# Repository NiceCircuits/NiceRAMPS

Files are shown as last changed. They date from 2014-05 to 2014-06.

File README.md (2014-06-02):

ramps_plus
==========
Forked from Ramps 1.4.

Improved version of RAMPS board with ribbon cable connecors and more.

Change log from Ramps 1.4:

- a few ribbon header connectors instead of many pinheaders

- schematic in KiCad

- compatibility with Arduino Due

- separate power supplies for heaters, bed and motors

- 0,5A OC outputs for driwing LED/fans

- SMT power transistors

- blade fuses

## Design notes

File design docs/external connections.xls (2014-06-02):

1 | heater1+ |  | Carriage | bed+ | panel
2 |  |  |  | bed-
3 | heater1- |  |  | bed_th
4 |  |  |  | bed_th
5 | heater2+ |  |  | endstopY
6 |  |  |  | endstopZ
7 | heater2- | g |  | motorY
8 |  |  |  | motorZ
9 | motorE1 |  |  | pwm led
10 | motorE1 |  |  | pwm fan
11 | motorE1 |  |  | pwm fan
12 | motorE1 |  |  | pwm fan
13 | motorE2
14 | motorE2
15 | motorE2
16 | motorE2
17 | pwm1 | fan1
18 | pwm2 | fan2
19 | pwm3 | fan3
20 | pwm4 | led
21 | pwm+
22 | pwm+
23 | GND-N.C.
24 | thermistor-
25 | thermistor1
26 | thermistor2
27 | endstop-
28 | endstop+
29 | endstopX1
30 | endstopX2
31 | motorX |  | Xstop
32 | motorX
33 | motorX
34 | motorX

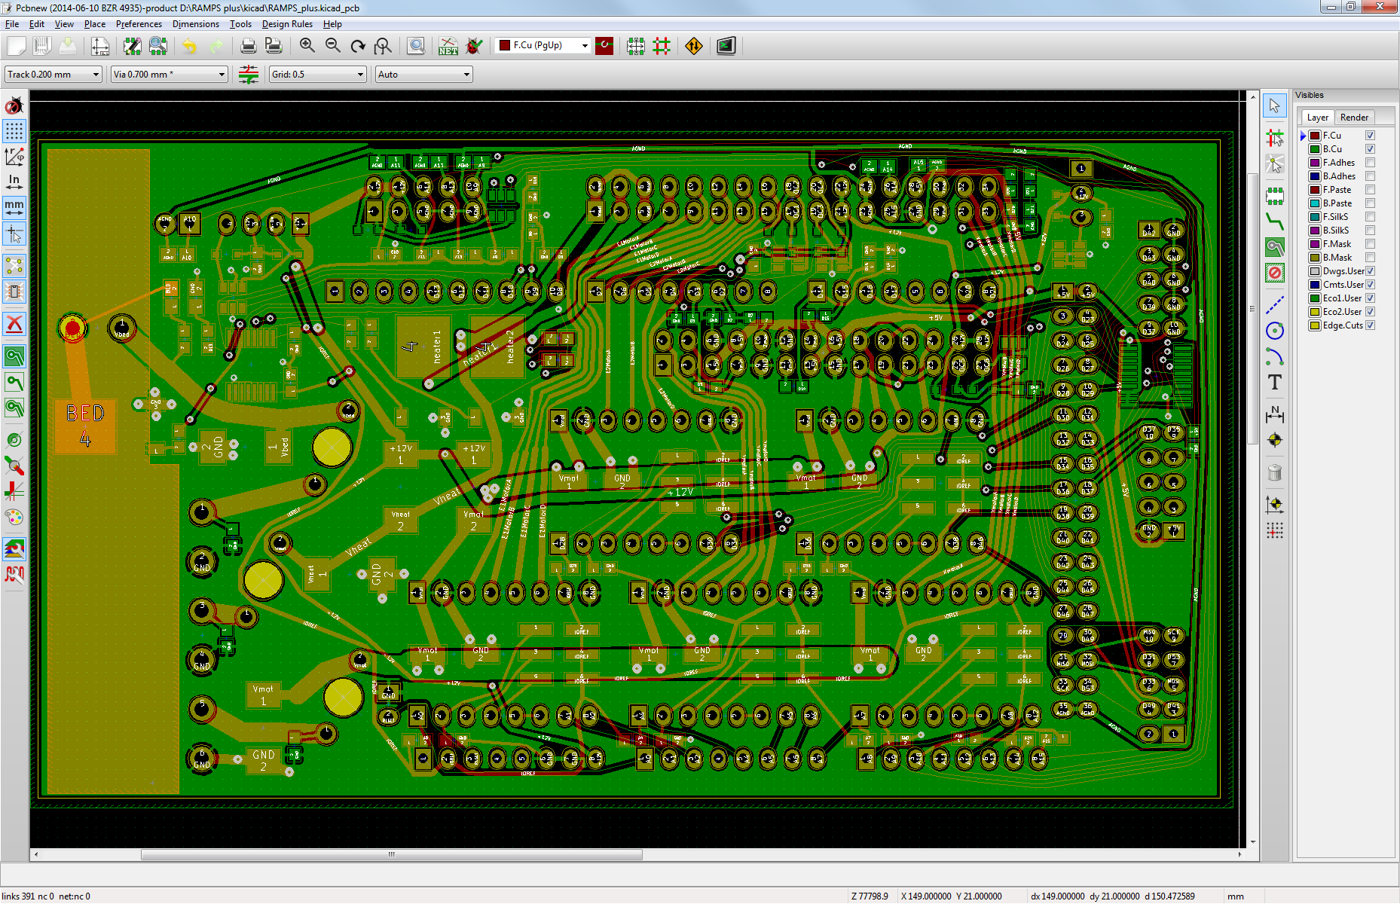
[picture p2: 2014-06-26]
kicad/routing.png

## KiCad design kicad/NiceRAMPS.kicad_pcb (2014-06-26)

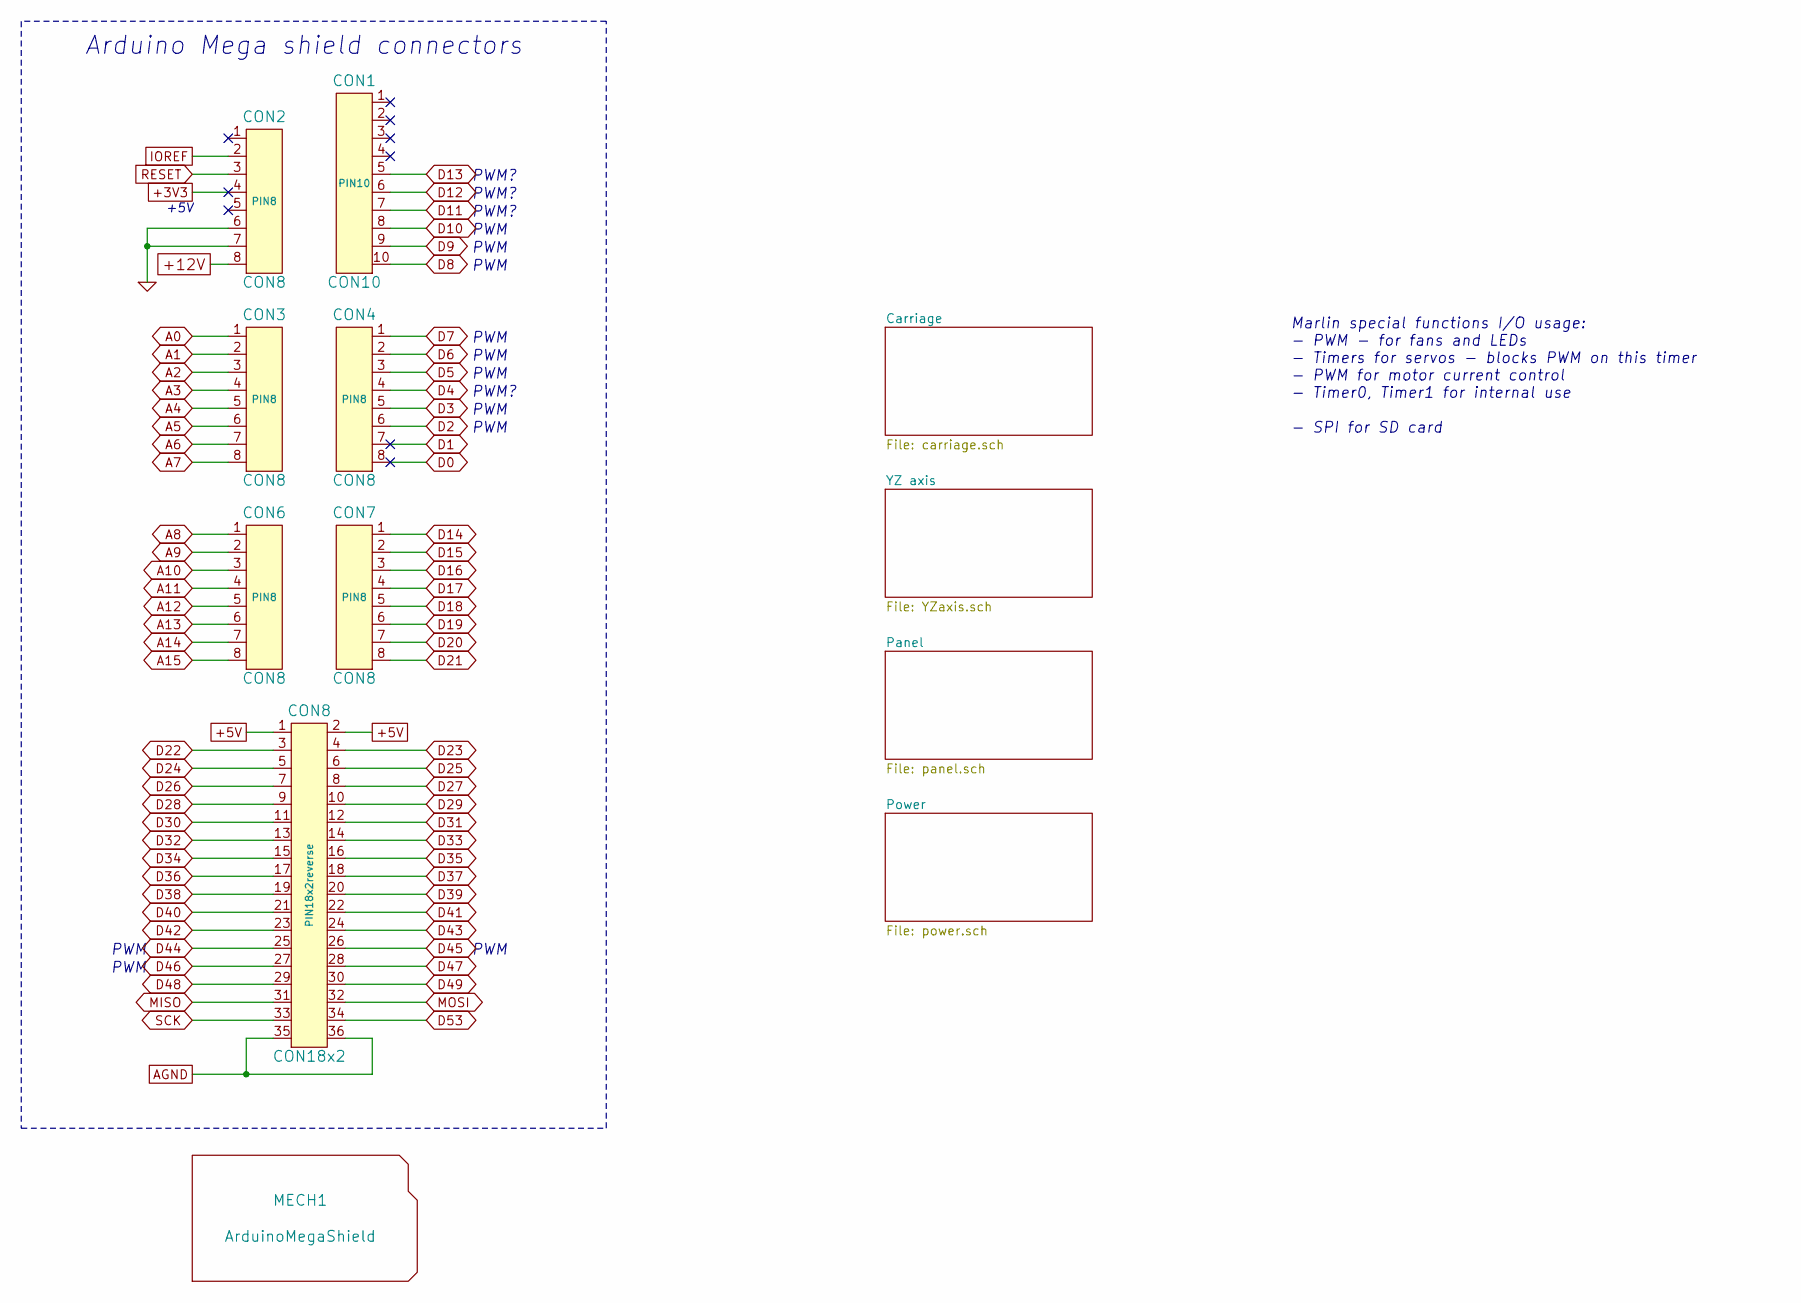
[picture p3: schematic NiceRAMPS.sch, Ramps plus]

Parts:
CON1: CON10; PIN10
CON2, CON3, CON4, CON6, CON7: CON8; PIN8
CON8: CON18x2; PIN18x2reverse
MECH1: ArduinoMegaShield

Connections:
+5V: CON8.1, CON8.2; also elsewhere on the board
+12V: CON2.8; also elsewhere on the board
A0: CON3.1; also elsewhere on the board
A1: CON3.2; also elsewhere on the board
A2: CON3.3; also elsewhere on the board
A4: CON3.5; also elsewhere on the board
A5: CON3.6; also elsewhere on the board
A6: CON3.7; also elsewhere on the board
A7: CON3.8; also elsewhere on the board
A8: CON6.1; also elsewhere on the board
A9: CON6.2; also elsewhere on the board
A10: CON6.3; also elsewhere on the board
A11: CON6.4; also elsewhere on the board
A12: CON6.5; also elsewhere on the board
A13: CON6.6; also elsewhere on the board
A14: CON6.7; also elsewhere on the board
A15: CON6.8; also elsewhere on the board
AGND: CON8.35, CON8.36; also elsewhere on the board
D2: CON4.6; also elsewhere on the board
D3: CON4.5; also elsewhere on the board
D4: CON4.4; also elsewhere on the board
D5: CON4.3; also elsewhere on the board
D6: CON4.2; also elsewhere on the board
D7: CON4.1; also elsewhere on the board
D8: CON1.10; also elsewhere on the board
D9: CON1.9; also elsewhere on the board
D10: CON1.8; also elsewhere on the board
D11: CON1.7; also elsewhere on the board
D12: CON1.6; also elsewhere on the board
D13: CON1.5; also elsewhere on the board
D14: CON7.1; also elsewhere on the board
D15: CON7.2; also elsewhere on the board
D16: CON7.3; also elsewhere on the board
D17: CON7.4; also elsewhere on the board
D20: CON7.7; also elsewhere on the board
D21: CON7.8; also elsewhere on the board
D23: CON8.4; also elsewhere on the board
D24: CON8.5; also elsewhere on the board
D25: CON8.6; also elsewhere on the board
D26: CON8.7; also elsewhere on the board
D27: CON8.8; also elsewhere on the board
D28: CON8.9; also elsewhere on the board
D29: CON8.10; also elsewhere on the board
D30: CON8.11; also elsewhere on the board
D31: CON8.12; also elsewhere on the board
D32: CON8.13; also elsewhere on the board
D33: CON8.14; also elsewhere on the board
D34: CON8.15; also elsewhere on the board
D35: CON8.16; also elsewhere on the board
D36: CON8.17; also elsewhere on the board
D37: CON8.18; also elsewhere on the board
D38: CON8.19; also elsewhere on the board
D39: CON8.20; also elsewhere on the board
D40: CON8.21; also elsewhere on the board
D41: CON8.22; also elsewhere on the board
D42: CON8.23; also elsewhere on the board
D43: CON8.24; also elsewhere on the board
D44: CON8.25; also elsewhere on the board
D45: CON8.26; also elsewhere on the board
D46: CON8.27; also elsewhere on the board
D47: CON8.28; also elsewhere on the board
D49: CON8.30; also elsewhere on the board
D53: CON8.34; also elsewhere on the board
GND: CON2.6, CON2.7; also elsewhere on the board
IOREF: CON2.2; also elsewhere on the board
MISO: CON8.31; also elsewhere on the board
MOSI: CON8.32; also elsewhere on the board
RESET: CON2.3; also elsewhere on the board
SCK: CON8.33; also elsewhere on the board

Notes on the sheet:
Arduino Mega shield connectors
PWM
Marlin special functions I/O usage: - PWM - for fans and LEDs - Timers for servos - blocks PWM on this timer - PWM for motor current control - Timer0, Timer1 for internal use - SPI for SD card
PWM?
+5V

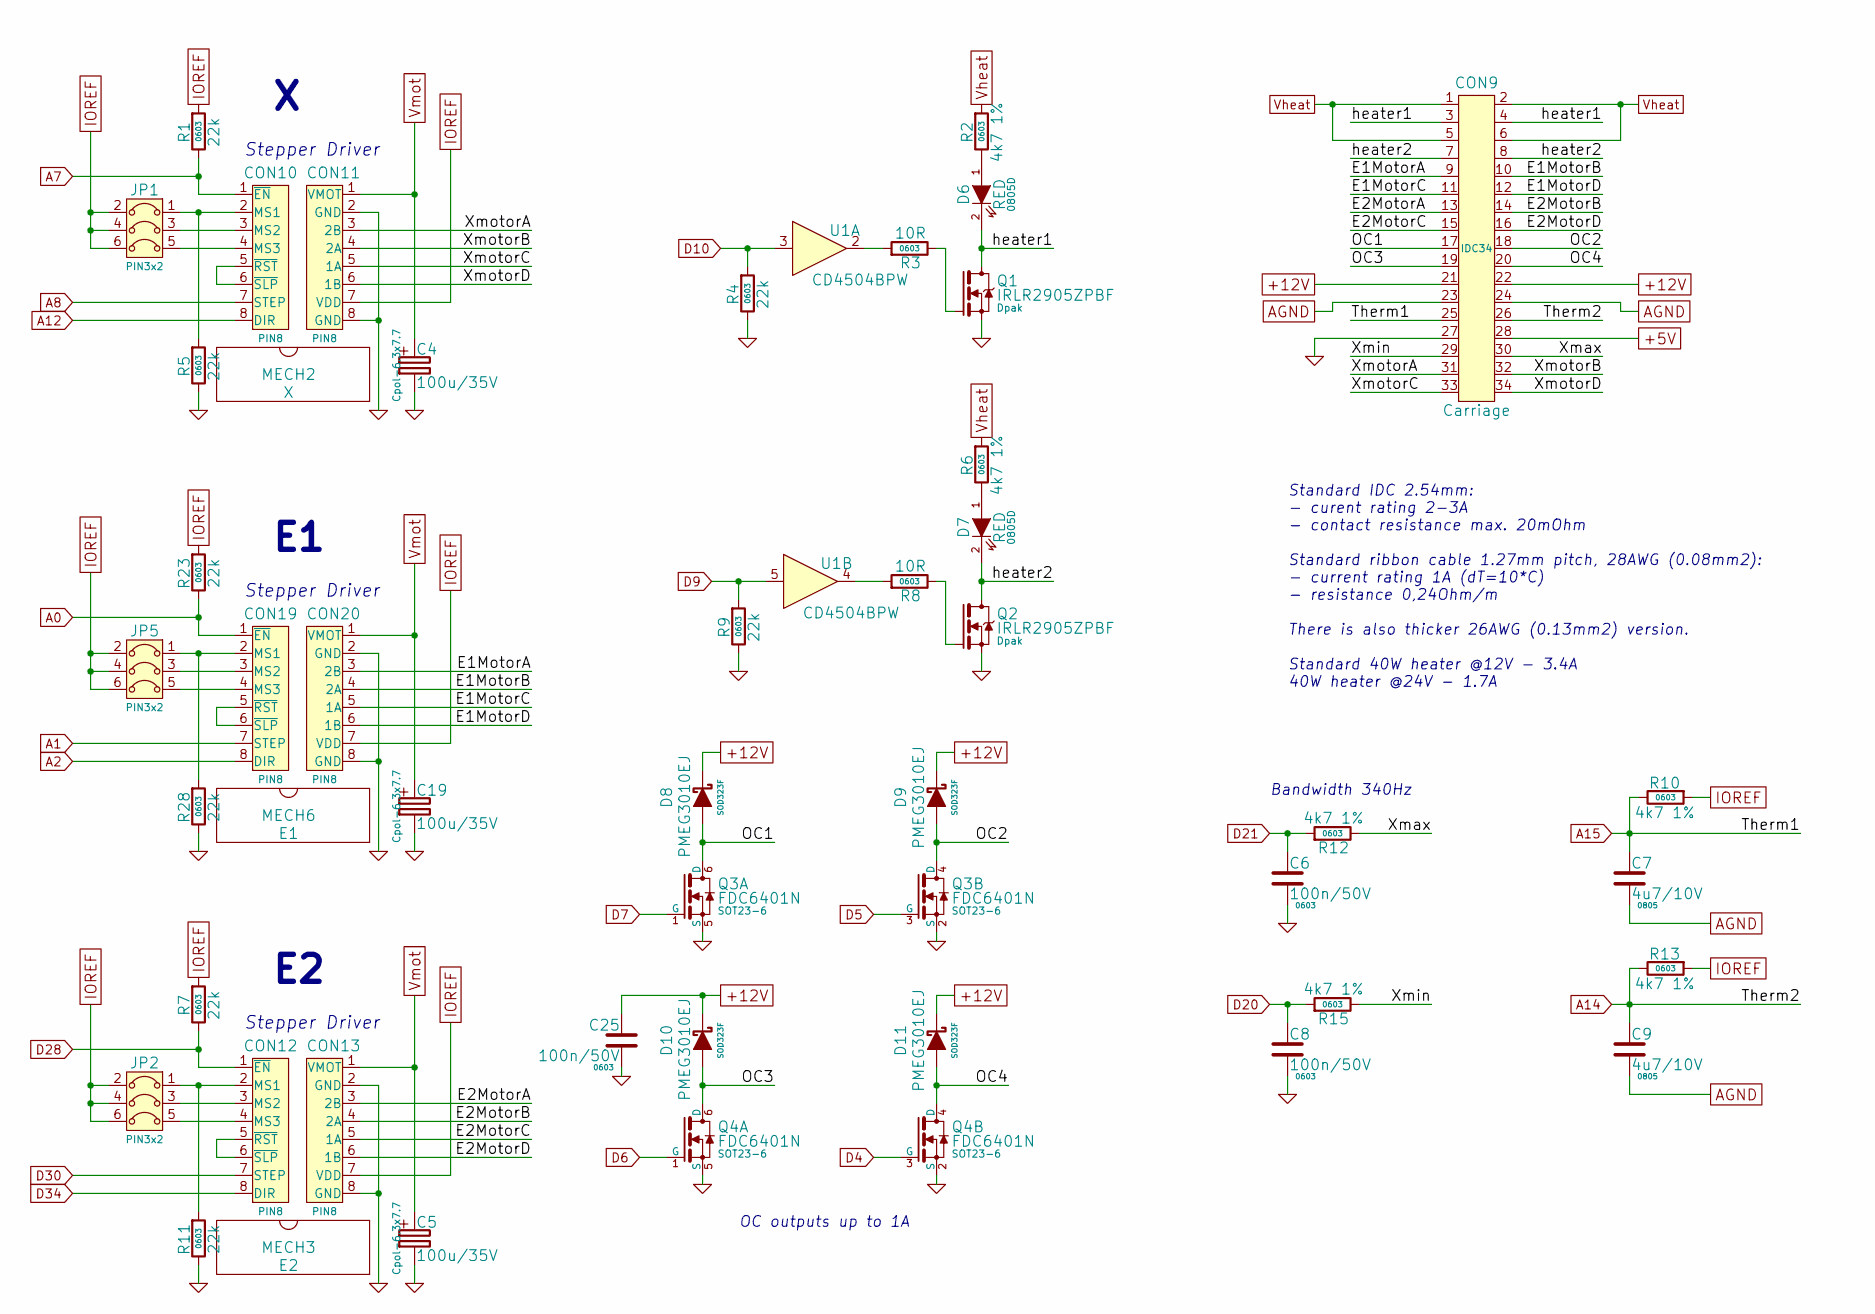
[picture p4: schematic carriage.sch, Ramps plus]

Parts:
C4, C5, C19: 100u/35V; Cpol-6.3x7.7
C6, C8, C25: 100n/50V; 0603
C7, C9: 4u7/10V; 0805
CON9: Carriage; IDC34
CON10, CON12, CON19: Stepstick_Left_Connector; PIN8
CON11, CON13, CON20: Stepstick_Right_Connector; PIN8
D6, D7: RED; 0805D
D8, D9, D10, D11: PMEG3010EJ; SOD323F
JP1, JP2, JP5: Jumper3; PIN3x2
MECH2: X
MECH3: E2
MECH6: E1
Q1, Q2: IRLR2905ZPBF; Dpak
Q3, Q4: FDC6401N; SOT23-6
R1, R4, R5, R7, R9, R11, R23, R28: 22k; 0603
R2, R6, R10, R12, R13, R15: 4k7 1%; 0603
R3, R8: 10R; 0603
U1: CD4504BPW; TSSOP16

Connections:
+5V: CON9.28; also elsewhere on the board
+12V: C25.1, CON9.21, CON9.22, D8.1, D9.1, D10.1, D11.1; also elsewhere on the board
/Carriage/E1MotorA: CON9.9, CON20.3 (2B)
/Carriage/E1MotorB: CON9.10, CON20.4 (2A)
/Carriage/E1MotorC: CON9.11, CON20.5 (1A)
/Carriage/E1MotorD: CON9.12, CON20.6 (1B)
/Carriage/E2MotorA: CON9.13, CON13.3 (2B)
/Carriage/E2MotorB: CON9.14, CON13.4 (2A)
/Carriage/E2MotorC: CON9.15, CON13.5 (1A)
/Carriage/E2MotorD: CON9.16, CON13.6 (1B)
/Carriage/OC1: CON9.17, D8.2, Q3.6 (D)
/Carriage/OC2: CON9.18, D9.2, Q3.4 (D)
/Carriage/OC3: CON9.19, D10.2, Q4.6 (D)
/Carriage/OC4: CON9.20, D11.2, Q4.4 (D)
/Carriage/Xmax: CON9.30, R12.2
/Carriage/Xmin: CON9.29, R15.2
/Carriage/XmotorA: CON9.31, CON11.3 (2B)
/Carriage/XmotorB: CON9.32, CON11.4 (2A)
/Carriage/XmotorC: CON9.33, CON11.5 (1A)
/Carriage/XmotorD: CON9.34, CON11.6 (1B)
/Carriage/heater1: CON9.3, CON9.4, D6.2 (K), Q1.4 (D)
/Carriage/heater2: CON9.7, CON9.8, D7.2 (K), Q2.4 (D)
A0: CON19.1 (~EN), R23.2; also elsewhere on the board
A1: CON19.7 (STEP); also elsewhere on the board
A2: CON19.8 (DIR); also elsewhere on the board
A7: CON10.1 (~EN), R1.2; also elsewhere on the board
A8: CON10.7 (STEP); also elsewhere on the board
A12: CON10.8 (DIR); also elsewhere on the board
A14: C9.1, CON9.26, R13.2; also elsewhere on the board
A15: C7.1, CON9.25, R10.2; also elsewhere on the board
AGND: C7.2, C9.2, CON9.23, CON9.24; also elsewhere on the board
D4: Q4.3 (G); also elsewhere on the board
D5: Q3.3 (G); also elsewhere on the board
D6: Q4.1 (G); also elsewhere on the board
D7: Q3.1 (G); also elsewhere on the board
D9: R9.1, U1.5 (IN2); also elsewhere on the board
D10: R4.1, U1.3 (IN1); also elsewhere on the board
D20: C8.1, R15.1; also elsewhere on the board
D21: C6.1, R12.1; also elsewhere on the board
D28: CON12.1 (~EN), R7.2; also elsewhere on the board
D30: CON12.7 (STEP); also elsewhere on the board
D34: CON12.8 (DIR); also elsewhere on the board
GND: C4.2, C5.2, C6.2, C8.2, C19.2, C25.2, CON9.27, CON11.2 (GND), CON11.8 (GND), CON13.2 (GND), CON13.8 (GND), CON20.2 (GND), CON20.8 (GND), Q1.3 (S), Q2.3 (S), Q3.2 (S), Q3.5 (S), Q4.2 (S), Q4.5 (S), R4.2, R5.2, R9.2, R11.2, R28.2; also elsewhere on the board
IOREF: CON11.7 (VDD), CON13.7 (VDD), CON20.7 (VDD), JP1.2, JP1.4, JP1.6, JP2.2, JP2.4, JP2.6, JP5.2, JP5.4, JP5.6, R1.1, R7.1, R10.1, R13.1, R23.1; also elsewhere on the board
unnamed: CON10.2 (MS1), JP1.1, R5.1
unnamed: CON10.3 (MS2), JP1.3
unnamed: CON10.4 (MS3), JP1.5
unnamed: CON10.5 (~RST), CON10.6 (~SLP)
unnamed: CON12.2 (MS1), JP2.1, R11.1
unnamed: CON12.3 (MS2), JP2.3
unnamed: CON12.4 (MS3), JP2.5
unnamed: CON12.5 (~RST), CON12.6 (~SLP)
unnamed: CON19.2 (MS1), JP5.1, R28.1
unnamed: CON19.3 (MS2), JP5.3
unnamed: CON19.4 (MS3), JP5.5
unnamed: CON19.5 (~RST), CON19.6 (~SLP)
unnamed: D6.1 (A), R2.2
unnamed: D7.1 (A), R6.2
unnamed: Q1.1 (G), R3.2
unnamed: Q2.1 (G), R8.2
unnamed: R3.1, U1.2 (OUT1)
unnamed: R8.1, U1.4 (OUT2)
Vheat: CON9.1, CON9.2, CON9.5, CON9.6, R2.1, R6.1; also elsewhere on the board
Vmot: C4.1, C5.1, C19.1, CON11.1 (VMOT), CON13.1 (VMOT), CON20.1 (VMOT); also elsewhere on the board

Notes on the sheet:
Standard IDC 2.54mm: - curent rating 2-3A - contact resistance max. 20mOhm Standard ribbon cable 1.27mm pitch, 28AWG (0.08mm2): - current rating 1A (dT=10*C) - resistance 0,24Ohm/m There is also thicker 26AWG (0.13mm2) version. Standard 40W heater @12V - 3.4A 40W heater @24V - 1.7A
Bandwidth 340Hz
OC outputs up to 1A
Stepper Driver

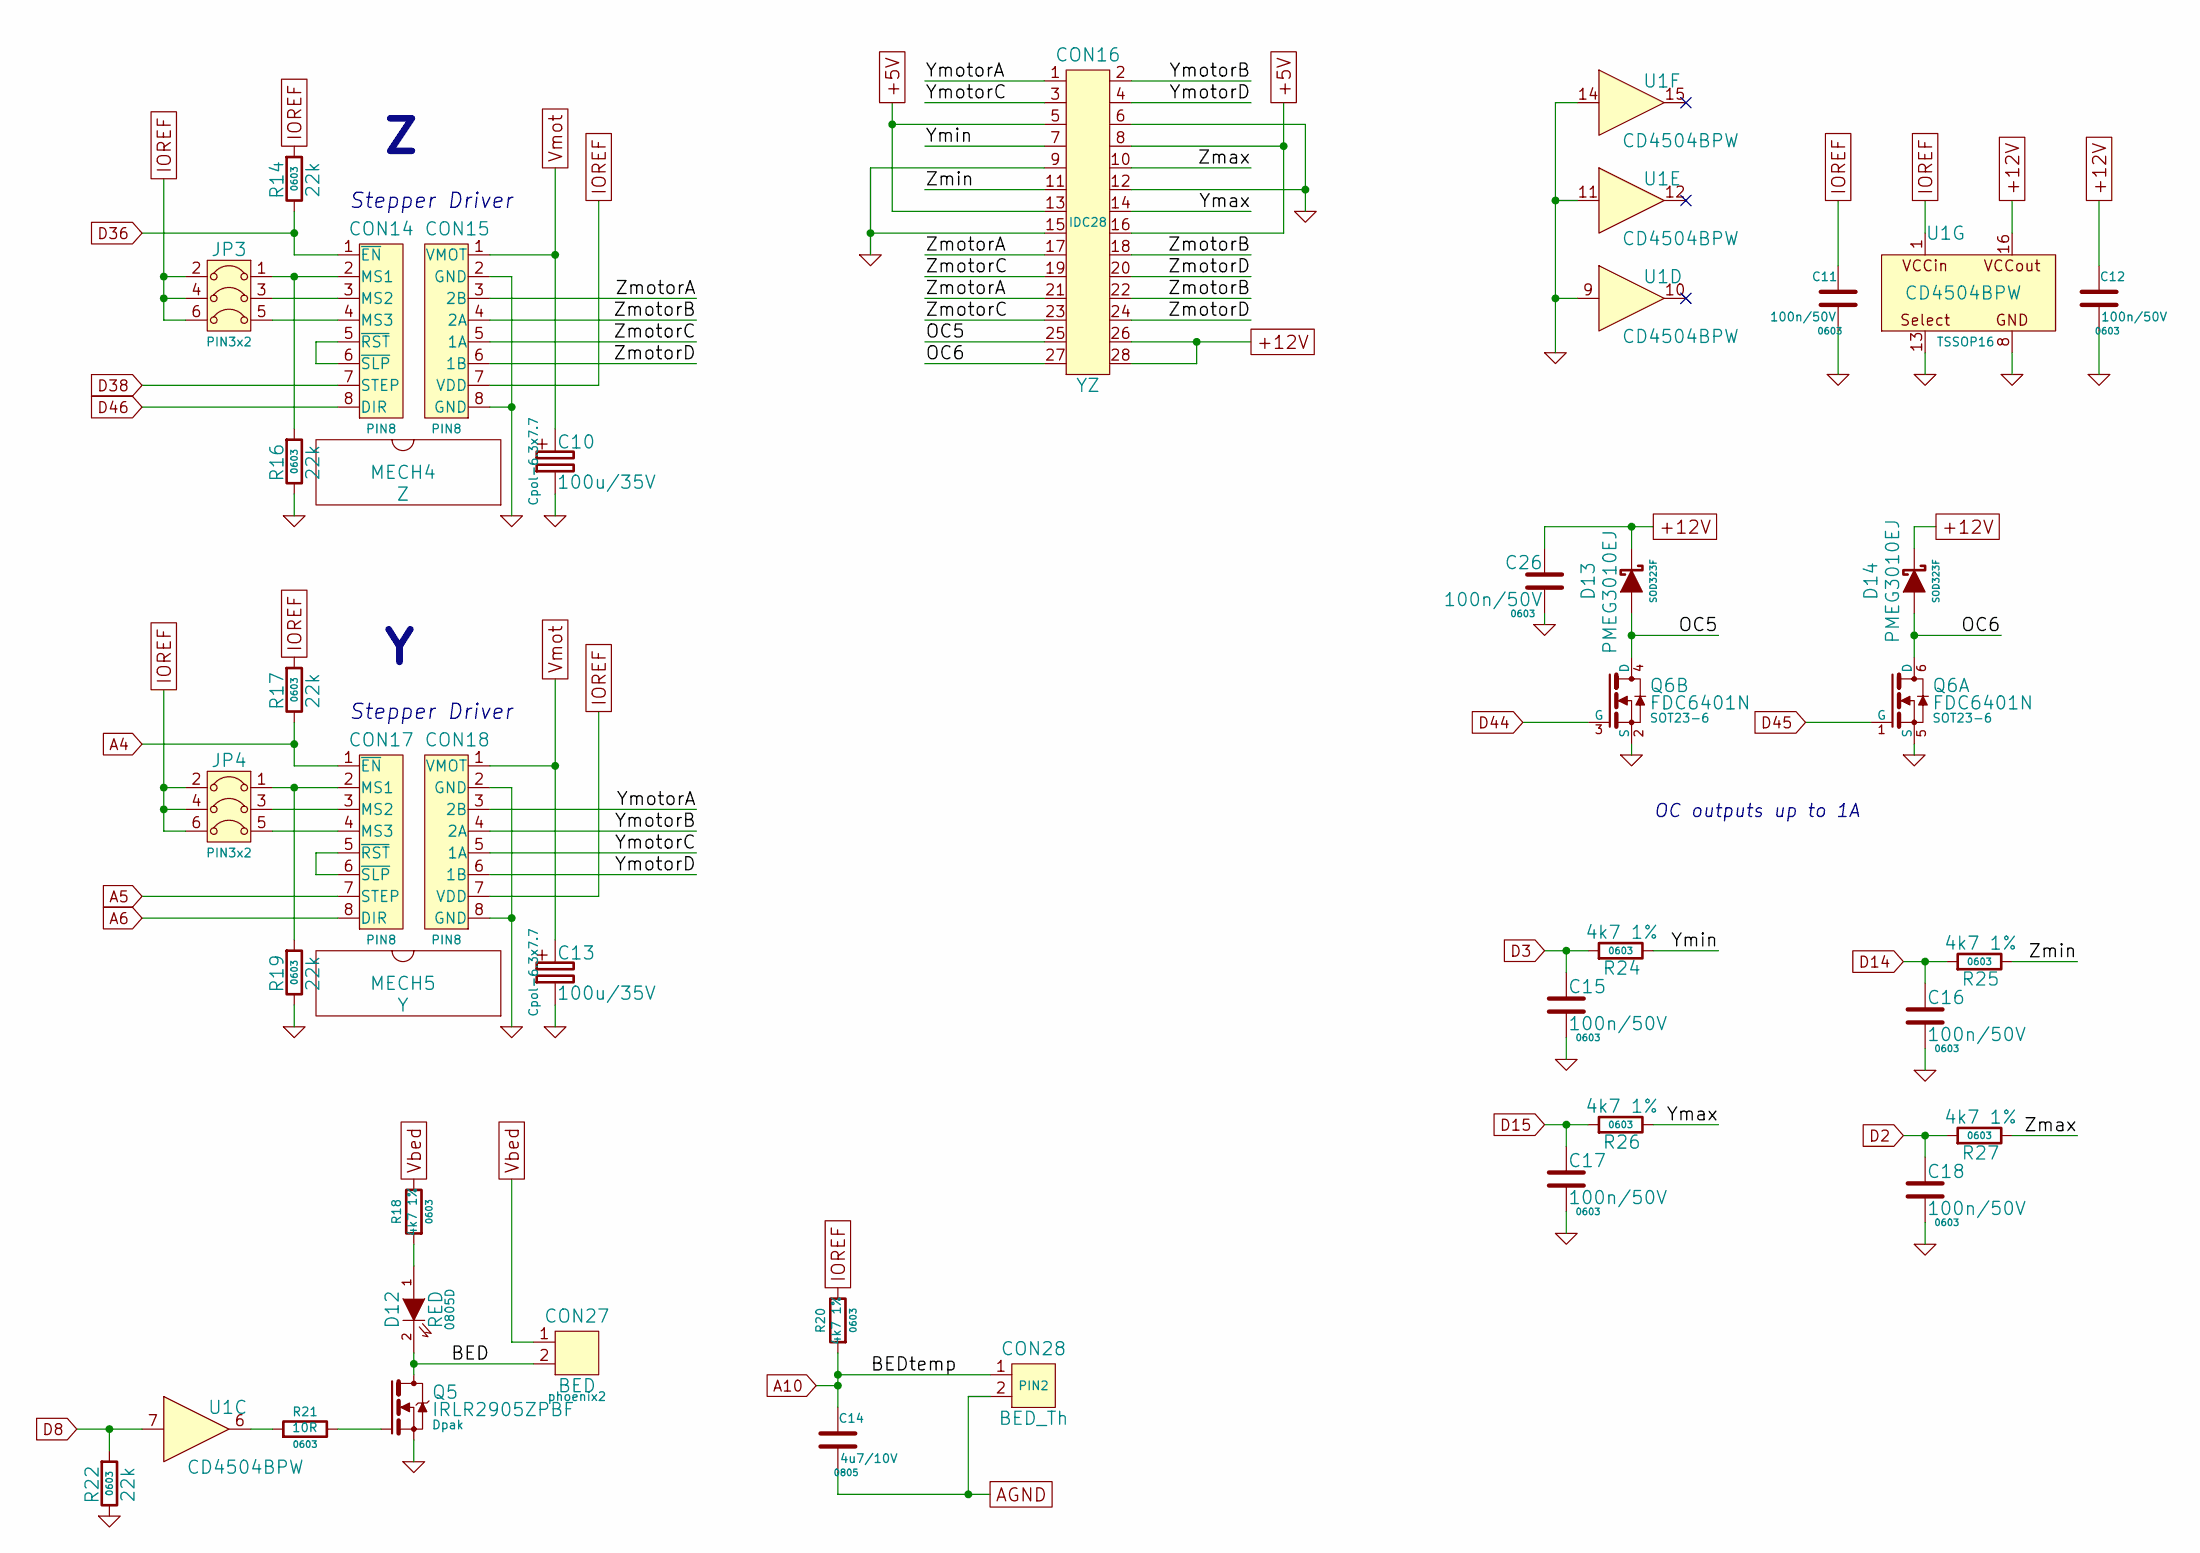
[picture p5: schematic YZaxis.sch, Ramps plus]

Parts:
C10, C13: 100u/35V; Cpol-6.3x7.7
C11, C12, C15, C16, C17, C18, C26: 100n/50V; 0603
C14: 4u7/10V; 0805
CON14, CON17: Stepstick_Left_Connector; PIN8
CON15, CON18: Stepstick_Right_Connector; PIN8
CON16: YZ; IDC28
CON27: BED; phoenix2
CON28: BED_Th; PIN2
D12: RED; 0805D
D13, D14: PMEG3010EJ; SOD323F
JP3, JP4: Jumper3; PIN3x2
MECH4: Z
MECH5: Y
Q5: IRLR2905ZPBF; Dpak
Q6: FDC6401N; SOT23-6
R14, R16, R17, R19, R22: 22k; 0603
R18, R20, R24, R25, R26, R27: 4k7 1%; 0603
R21: 10R; 0603
U1: CD4504BPW; TSSOP16

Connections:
+5V: CON16.5, CON16.8, CON16.13, CON16.16; also elsewhere on the board
+12V: C12.1, C26.1, CON16.26, CON16.28, D13.1, D14.1, U1.16 (VDD); also elsewhere on the board
/YZ axis/BED: CON27.2, D12.2 (K), Q5.4 (D)
/YZ axis/OC5: CON16.25, D13.2, Q6.4 (D)
/YZ axis/OC6: CON16.27, D14.2, Q6.6 (D)
/YZ axis/Ymax: CON16.14, R26.2
/YZ axis/Ymin: CON16.7, R24.2
/YZ axis/YmotorA: CON16.1, CON18.3 (2B)
/YZ axis/YmotorB: CON16.2, CON18.4 (2A)
/YZ axis/YmotorC: CON16.3, CON18.5 (1A)
/YZ axis/YmotorD: CON16.4, CON18.6 (1B)
/YZ axis/Zmax: CON16.10, R27.2
/YZ axis/Zmin: CON16.11, R25.2
/YZ axis/ZmotorA: CON15.3 (2B), CON16.17, CON16.21
/YZ axis/ZmotorB: CON15.4 (2A), CON16.18, CON16.22
/YZ axis/ZmotorC: CON15.5 (1A), CON16.19, CON16.23
/YZ axis/ZmotorD: CON15.6 (1B), CON16.20, CON16.24
A4: CON17.1 (~EN), R17.2; also elsewhere on the board
A5: CON17.7 (STEP); also elsewhere on the board
A6: CON17.8 (DIR); also elsewhere on the board
A10: C14.1, CON28.1, R20.1; also elsewhere on the board
AGND: C14.2, CON28.2; also elsewhere on the board
D2: C18.1, R27.1; also elsewhere on the board
D3: C15.1, R24.1; also elsewhere on the board
D8: R22.1, U1.7 (IN3); also elsewhere on the board
D14: C16.1, R25.1; also elsewhere on the board
D15: C17.1, R26.1; also elsewhere on the board
D36: CON14.1 (~EN), R14.2; also elsewhere on the board
D38: CON14.7 (STEP); also elsewhere on the board
D44: Q6.3 (G); also elsewhere on the board
D45: Q6.1 (G); also elsewhere on the board
D46: CON14.8 (DIR); also elsewhere on the board
GND: C10.2, C11.2, C12.2, C13.2, C15.2, C16.2, C17.2, C18.2, C26.2, CON15.2 (GND), CON15.8 (GND), CON16.6, CON16.9, CON16.12, CON16.15, CON18.2 (GND), CON18.8 (GND), Q5.3 (S), Q6.2 (S), Q6.5 (S), R16.2, R19.2, R22.2, U1.8 (GND), U1.9 (IN4), U1.11 (IN5), U1.13 (GND), U1.14 (IN6); also elsewhere on the board
IOREF: C11.1, CON15.7 (VDD), CON18.7 (VDD), JP3.2, JP3.4, JP3.6, JP4.2, JP4.4, JP4.6, R14.1, R17.1, R20.2, U1.1 (VCC); also elsewhere on the board
unnamed: CON14.2 (MS1), JP3.1, R16.1
unnamed: CON14.3 (MS2), JP3.3
unnamed: CON14.4 (MS3), JP3.5
unnamed: CON14.5 (~RST), CON14.6 (~SLP)
unnamed: CON17.2 (MS1), JP4.1, R19.1
unnamed: CON17.3 (MS2), JP4.3
unnamed: CON17.4 (MS3), JP4.5
unnamed: CON17.5 (~RST), CON17.6 (~SLP)
unnamed: D12.1 (A), R18.1
unnamed: Q5.1 (G), R21.2
unnamed: R21.1, U1.6 (OUT3)
Vbed: CON27.1, R18.2; also elsewhere on the board
Vmot: C10.1, C13.1, CON15.1 (VMOT), CON18.1 (VMOT); also elsewhere on the board

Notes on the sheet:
OC outputs up to 1A
Stepper Driver

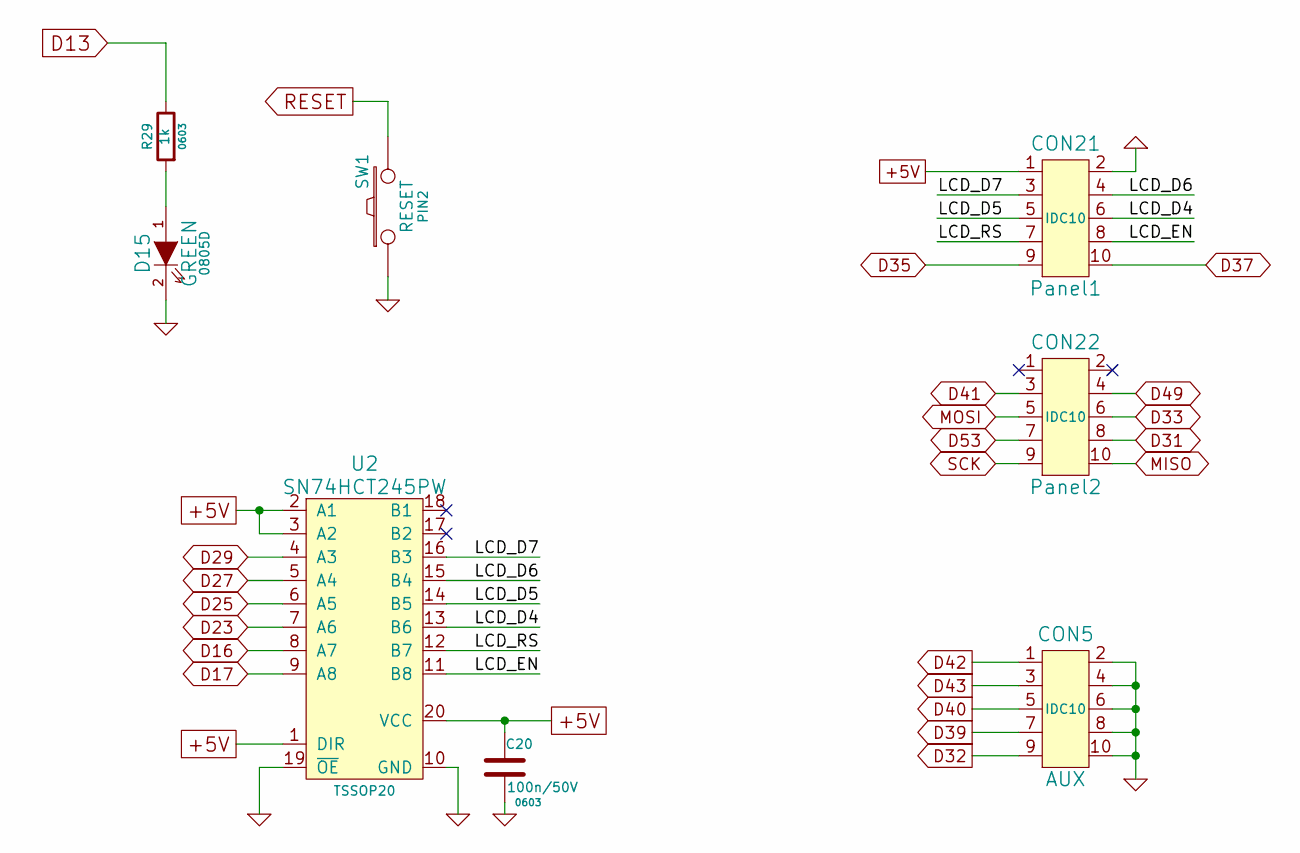
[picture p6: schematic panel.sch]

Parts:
C20: 100n/50V; 0603
CON5: AUX; IDC10
CON21: Panel1; IDC10
CON22: Panel2; IDC10
D15: GREEN; 0805D
R29: 1k; 0603
SW1: RESET; PIN2
U2: SN74HCT245PW; TSSOP20

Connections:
+5V: C20.1, CON21.1, U2.1 (DIR), U2.2 (A1), U2.3 (A2), U2.20 (VCC); also elsewhere on the board
/Panel/LCD_D4: CON21.6, U2.13 (B6)
/Panel/LCD_D5: CON21.5, U2.14 (B5)
/Panel/LCD_D6: CON21.4, U2.15 (B4)
/Panel/LCD_D7: CON21.3, U2.16 (B3)
/Panel/LCD_EN: CON21.8, U2.11 (B8)
/Panel/LCD_RS: CON21.7, U2.12 (B7)
D13: R29.2; also elsewhere on the board
D16: U2.8 (A7); also elsewhere on the board
D17: U2.9 (A8); also elsewhere on the board
D23: U2.7 (A6); also elsewhere on the board
D25: U2.6 (A5); also elsewhere on the board
D27: U2.5 (A4); also elsewhere on the board
D29: U2.4 (A3); also elsewhere on the board
D31: CON22.8; also elsewhere on the board
D32: CON5.9; also elsewhere on the board
D33: CON22.6; also elsewhere on the board
D35: CON21.9; also elsewhere on the board
D37: CON21.10; also elsewhere on the board
D39: CON5.7; also elsewhere on the board
D40: CON5.5; also elsewhere on the board
D41: CON22.3; also elsewhere on the board
D42: CON5.1; also elsewhere on the board
D43: CON5.3; also elsewhere on the board
D49: CON22.4; also elsewhere on the board
D53: CON22.7; also elsewhere on the board
GND: C20.2, CON5.2, CON5.4, CON5.6, CON5.8, CON5.10, CON21.2, D15.2 (K), SW1.1, U2.10 (GND), U2.19 (~OE); also elsewhere on the board
MISO: CON22.10; also elsewhere on the board
MOSI: CON22.5; also elsewhere on the board
unnamed: D15.1 (A), R29.1
RESET: SW1.2; also elsewhere on the board
SCK: CON22.9; also elsewhere on the board

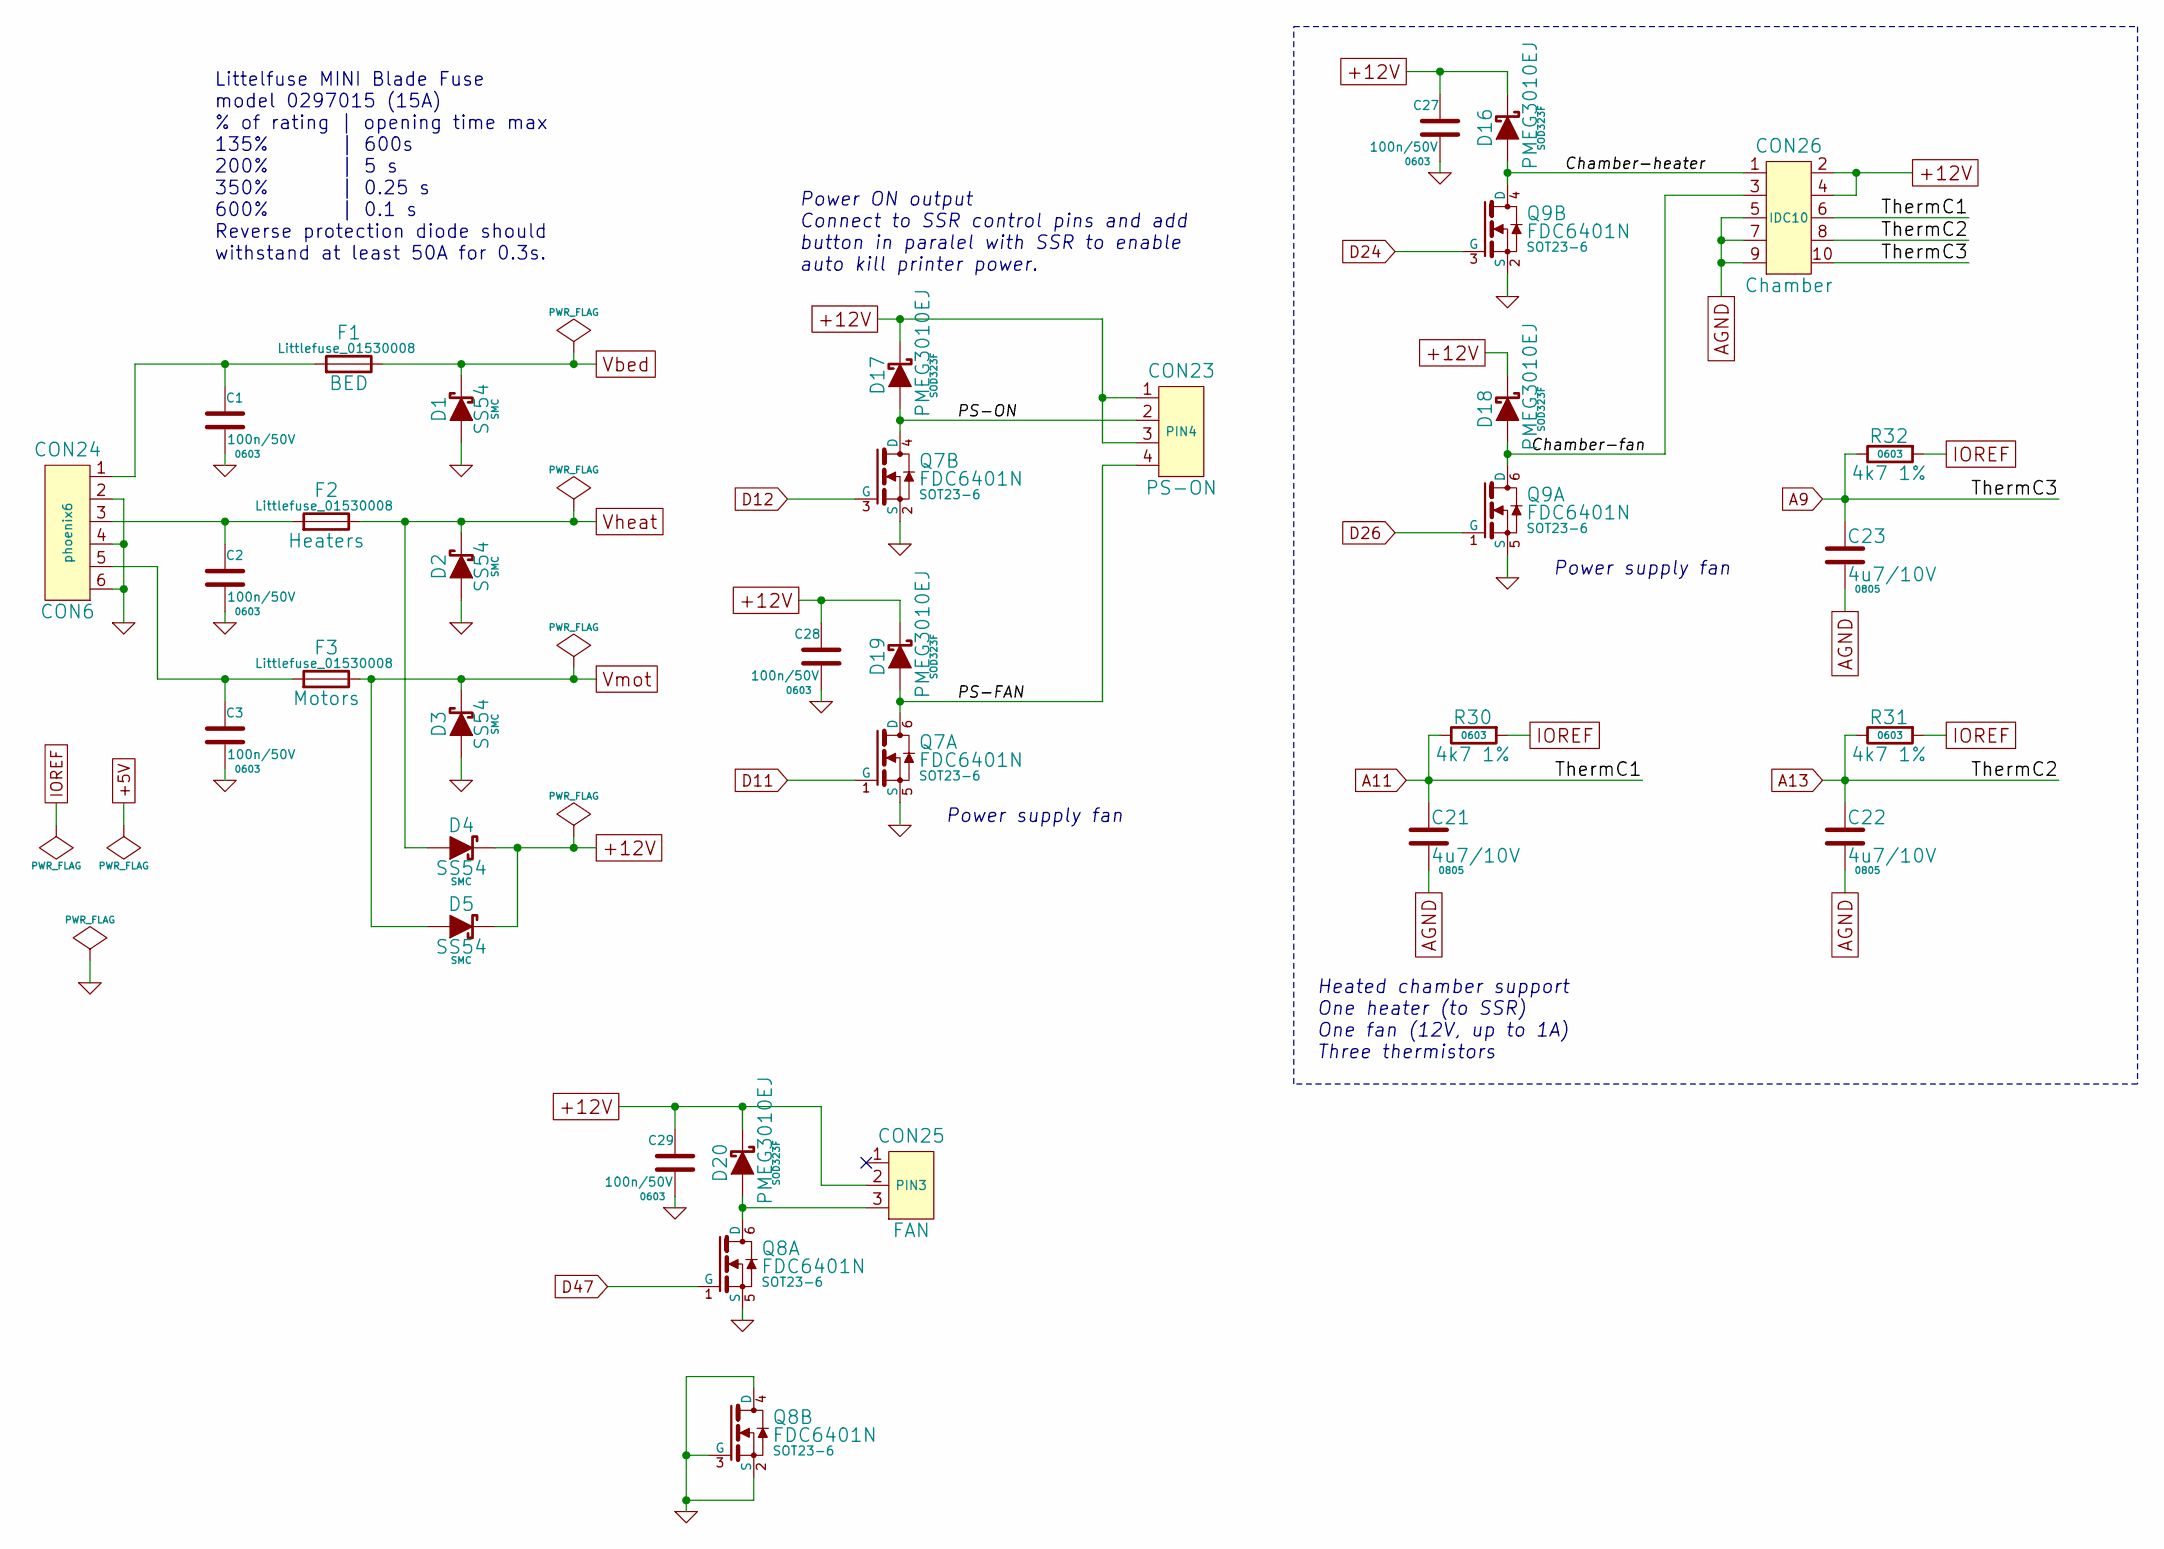
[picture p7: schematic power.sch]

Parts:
C1, C2, C3, C27, C28, C29: 100n/50V; 0603
C21, C22, C23: 4u7/10V; 0805
CON23: PS-ON; PIN4
CON24: CON6; phoenix6
CON25: FAN; PIN3
CON26: Chamber; IDC10
D1, D2, D3, D4, D5: SS54; SMC
D16, D17, D18, D19, D20: PMEG3010EJ; SOD323F
F1: BED; Littlefuse_01530008
F2: Heaters; Littlefuse_01530008
F3: Motors; Littlefuse_01530008
Q7, Q8, Q9: FDC6401N; SOT23-6
R30, R31, R32: 4k7 1%; 0603

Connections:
+12V: C27.1, C28.1, C29.1, CON23.1, CON23.3, CON25.2, CON26.2, CON26.4, D4.1, D5.1, D16.1, D17.1, D18.1, D19.1, D20.1; also elsewhere on the board
/Power/Chamber-fan: CON26.3, D18.2, Q9.6 (D)
/Power/Chamber-heater: CON26.1, D16.2, Q9.4 (D)
/Power/PS-FAN: CON23.4, D19.2, Q7.6 (D)
/Power/PS-ON: CON23.2, D17.2, Q7.4 (D)
A9: C23.1, CON26.10, R32.2; also elsewhere on the board
A11: C21.1, CON26.6, R30.2; also elsewhere on the board
A13: C22.1, CON26.8, R31.2; also elsewhere on the board
AGND: C21.2, C22.2, C23.2, CON26.5, CON26.7, CON26.9; also elsewhere on the board
D11: Q7.1 (G); also elsewhere on the board
D12: Q7.3 (G); also elsewhere on the board
D24: Q9.3 (G); also elsewhere on the board
D26: Q9.1 (G); also elsewhere on the board
D47: Q8.1 (G); also elsewhere on the board
GND: C1.2, C2.2, C3.2, C27.2, C28.2, C29.2, CON24.2, CON24.4, CON24.6, D1.2, D2.2, D3.2, Q7.2 (S), Q7.5 (S), Q8.2 (S), Q8.3 (G), Q8.4 (D), Q8.5 (S), Q9.2 (S), Q9.5 (S); also elsewhere on the board
IOREF: R30.1, R31.1, R32.1; also elsewhere on the board
unnamed: C1.1, CON24.1, F1.1
unnamed: C2.1, CON24.3, F2.1
unnamed: C3.1, CON24.5, F3.1
unnamed: CON25.3, D20.2, Q8.6 (D)
Vbed: D1.1, F1.2; also elsewhere on the board
Vheat: D2.1, D4.2, F2.2; also elsewhere on the board
Vmot: D3.1, D5.2, F3.2; also elsewhere on the board

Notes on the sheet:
Littelfuse MINI Blade Fuse model 0297015 (15A) % of rating | opening time max 135% | 600s 200% | 5 s 350% | 0.25 s 600% | 0.1 s Reverse protection diode should withstand at least 50A for 0.3s.
Power ON output Connect to SSR control pins and add button in paralel with SSR to enable auto kill printer power.
Power supply fan
Heated chamber support One heater (to SSR) One fan (12V, up to 1A) Three thermistors

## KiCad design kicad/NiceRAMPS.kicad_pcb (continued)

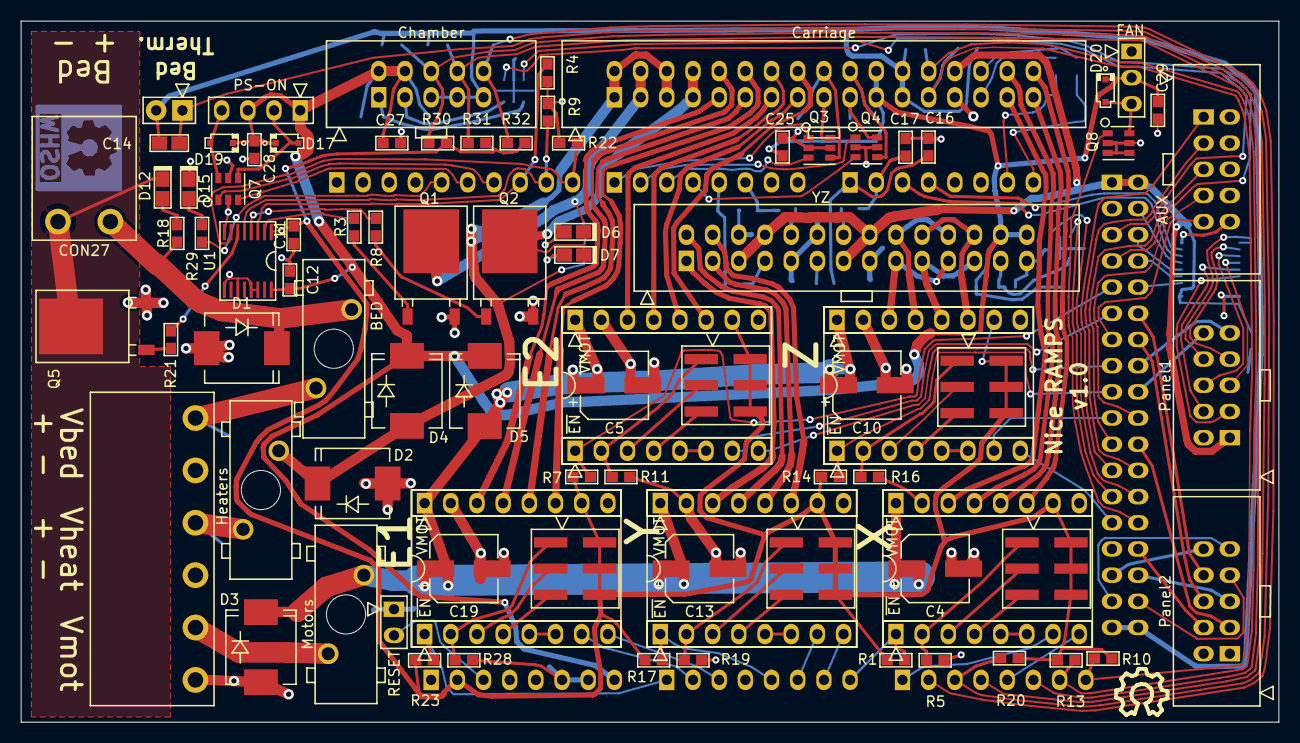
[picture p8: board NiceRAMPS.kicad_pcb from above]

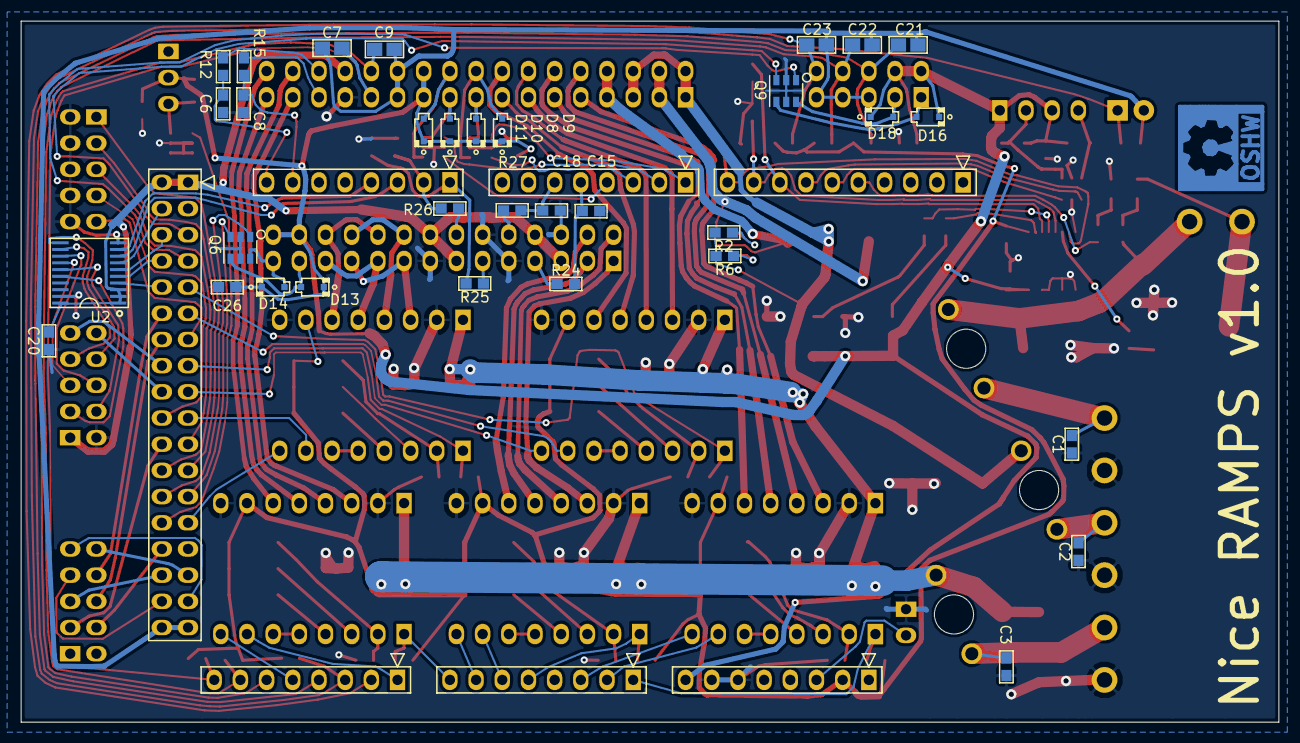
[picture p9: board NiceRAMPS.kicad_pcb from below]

Board: 2 copper layers, 122.0 x 68.0 mm, 135 parts (41 on the bottom side), 151 nets.

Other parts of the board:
SYM: Symbol_OSHW-Logo_SilkScreen_07Jul2012; Symbol_OSHW-Logo_SilkScreen_1
SYM#2: Symbol_OSHW-Logo_CopperTop_Negative_07Jul2012; Symbol_OSHW-Logo_CopperTop_Negative

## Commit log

2014-04-08 Start draw schematic
    References: #1 #5
    [RAMPS_plus.sch]
2014-04-08 Draw schematic
    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
    [$RAMPS_plus.sch, RAMPS_plus.kicad_pcb, stepper.sch]
2014-04-15 Draw schematic
    Added 40109 translators to drive MOSFET's.
    References: #1 #5 #13 #9
    Close #6
    [$RAMPS_plus.sch, RAMPS_plus.sch, carriage.sch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]
2014-04-16 Draw schematic
    Added sheet for panel connector and sheet for Y axis circuits.
    Added ULN2803
    References: #1 #11 #7 #5
    Close #13
    [RAMPS_plus.sch, Yaxis.sch, carriage.sch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]
2014-04-16 Draw schematic
    Commit before trying newer version of KiCad
    [RAMPS_plus.kicad_pcb, RAMPS_plus.sch, Yaxis.sch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]
2014-05-09 Draw schematic
    Finished redrawing basic RAMPS schematic
    References: #1 #4 #7 #15
    Close #5 #17 #18
    [RAMPS_plus.sch, Yaxis.sch, carriage.sch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]
2014-05-11 Change components to my own
    References: #1 #19
    [RAMPS_plus.sch, Yaxis.sch, carriage.sch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]
2014-05-22 Add YZ connector. Add endstop filters.
    Close #23
    References: #3 #20
    [RAMPS_plus.sch, YZaxis.sch, Yaxis.sch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]
2014-06-02 Add panel connectors. Minor ERC fixes.
    References: #11
    [RAMPS_plus.sch, YZaxis.sch, carriage.sch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]
2014-06-03 Change CD40109 to CD4504
    [RAMPS_plus.sch, YZaxis.sch, carriage.sch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]
2014-06-03 Add translators for LCD
    ref #11
    [panel.sch]
2014-06-07 Change ULN2803 to discrete MOSFET's FDC6401N
    Close #7
    [RAMPS_plus.sch, YZaxis.sch, carriage.sch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]
2014-06-08 Extract power supply circuits to another sheet. Add power off circuit.
    [RAMPS_plus.sch, YZaxis.sch, carriage.sch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]
2014-06-08 Change stepstick signal voltage to IOREF.
    reference #9
    close #21
    [YZaxis.sch, carriage.sch]
2014-06-08 Add AUX connectro for a few buttons or so
    close #14
    [RAMPS_plus.sch, YZaxis.sch, carriage.sch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]
2014-06-08 Added fan connectors for electronics and power supply
    close #15
    [RAMPS_plus.sch, YZaxis.sch, carriage.sch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]
2014-06-08 Add heated chamber support
    close #22
    [power.sch]
2014-06-12 Add footprint informations
    [RAMPS_plus.sch, YZaxis.sch, carriage.sch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]
2014-06-13 Place arduino shield connectors
    [RAMPS_plus.kicad_pcb, RAMPS_plus.sch, panel.sch]
2014-06-14 Place components
    [RAMPS_plus.kicad_pcb, RAMPS_plus.sch, YZaxis.sch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]
2014-06-14 Change jumpers to SMD
    [RAMPS_plus.kicad_pcb]
2014-06-14 Add bed connector. Routing.
    [RAMPS_plus.kicad_pcb, RAMPS_plus.sch, YZaxis.sch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]
2014-06-14 Change 1A diodes. Add capacitors next to OC outputs. Place.
    [RAMPS_plus.kicad_pcb, YZaxis.sch, carriage.sch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]
2014-06-15 Fix panel connections. Place.
    [RAMPS_plus.sch, YZaxis.sch, carriage.sch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]
2014-06-15 Place. Add design rules (Merkar, 6/8mil)
    [RAMPS_plus.kicad_pcb]
2014-06-15 Add autorouted board (for reference)
    [RAMPS_plus.dsn, RAMPS_plus.kicad_pcb]
2014-06-15 Start routing.
    [RAMPS_plus.dsn, RAMPS_plus.kicad_pcb]
2014-06-22 Swap pins
    [RAMPS_plus.kicad_pcb, RAMPS_plus.sch, YZaxis.sch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]
2014-06-23 Exchange stepstick connections.
    Simplify layout
    [RAMPS_plus.kicad_pcb, YZaxis.sch, carriage.sch]
2014-06-23 Pin swap. Route.
    [RAMPS_plus.dsn, RAMPS_plus.kicad_pcb, YZaxis.sch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]
2014-06-24 Add AGND. Route.
    close #27
    [RAMPS_plus.dsn, RAMPS_plus.kicad_pcb, RAMPS_plus.sch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]
2014-06-24 Route.
    Routed board with some minor DRC issues.
    [RAMPS_plus.dsn, RAMPS_plus.kicad_pcb, YZaxis.sch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]
2014-06-26 Fix DRC issues.
    [RAMPS_plus.kicad_pcb]
2014-06-26 Route. Generate gerber.
    [RAMPS_plus-B_Cu.gbl, RAMPS_plus-B_Mask.gbs, RAMPS_plus-B_SilkS.gbo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]
2014-06-26 Fix vias. generate gerber.
    [RAMPS_plus-B_Cu.gbl, RAMPS_plus-B_Mask.gbs, RAMPS_plus-B_SilkS.gbo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]
2014-06-26 Organize silkscreen.
    [RAMPS_plus-B_Cu.gbl, RAMPS_plus-B_Mask.gbs, RAMPS_plus-B_SilkS.gbo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]
2014-06-26 Rename and delete files
    [NiceRAMPS.kicad_pcb, NiceRAMPS.sch, RAMPS_plus.dsn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]
2014-06-26 Gerber rename
    [NiceRAMPS.gbl, NiceRAMPS.gbo, NiceRAMPS.gbs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]
